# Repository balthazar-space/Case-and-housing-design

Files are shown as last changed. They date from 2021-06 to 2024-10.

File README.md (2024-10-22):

# Balthazar

Open-hardware laptop computer modules description and concept.

These are designs of  modules as presented at https://balthazar.space/wiki/Balthazar with the main aim for team access. See the [main repository](https://github.com/balthazar-space/balthazar) for other designs.

# Balthazar case and design 

Balthazar's casing or a housing and its design.

This is the place for pictures of casing design and 3D ready-to-print files and other design proposals.

A new reorganisation of the files starting from the 1st ever version v0.1, going over to the current v0.2.

Each future version will have its iteration version, containing pictures of made elements and assembled casings, Blender models, 
3D print-ready files, documentation usually encapsulated in README.md file, and adjoining extra files to ease and explain assembly process. 
We will try to accomodate all of the aspects. 

In the case of modifying the case, we encourage you to precisely indicate and include short descriptions of casing openings 
to a certain SoM (systems on a Module) and outputs.

Those files will be updated as we move on and as revisions change to a final look and also materials will vary.
We will ensure that home and industrial versions are made, so that everyone can make case, wheather as a school project, 
cheaper home D-I-Y or ready for a mass production.

About the file formats - the truth is following.
The issues we are encountering and it is as it might be
somewhat problematic with Open Source software. 
CAD is complicated on Linux, as it is a big
business - and we must fight for it to have it more open.

However to be more professional in those both directions, we will try to be reluctantly compliant, 
balancing between the industry and our community.  

You can watch .dxf files only with Autocad software and also on your mobile 
device with a few dedicated apps. 
DWG files you can see also with Adobe programs, but because they are
basically all just drawings they will be shown as 2d drawings then. 
Only in Autocad you can see them as 3D objects.
So you see the dxf files, but if you have no Autocad, you can not do anything with them.
Bummer that is and out of our reach, right now.

Also there are hi res .step files as well as .stl.
Those should be pretty much compatible with many Open Source software and industrial standards.

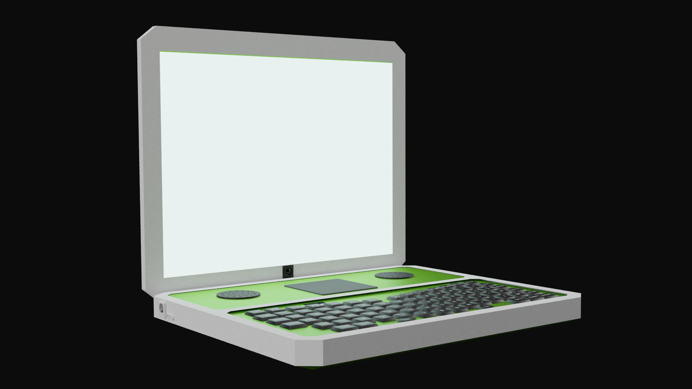
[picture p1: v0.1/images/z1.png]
v0.1


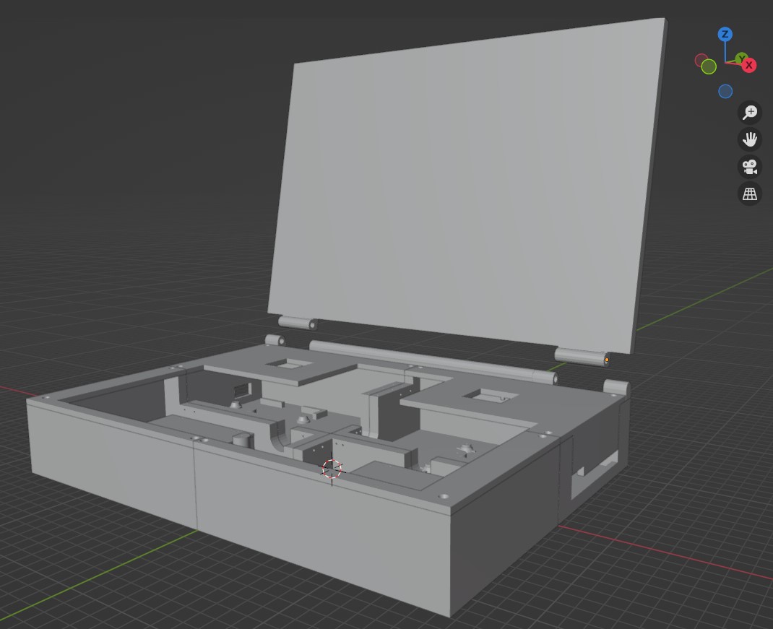
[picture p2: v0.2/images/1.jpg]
v0.2


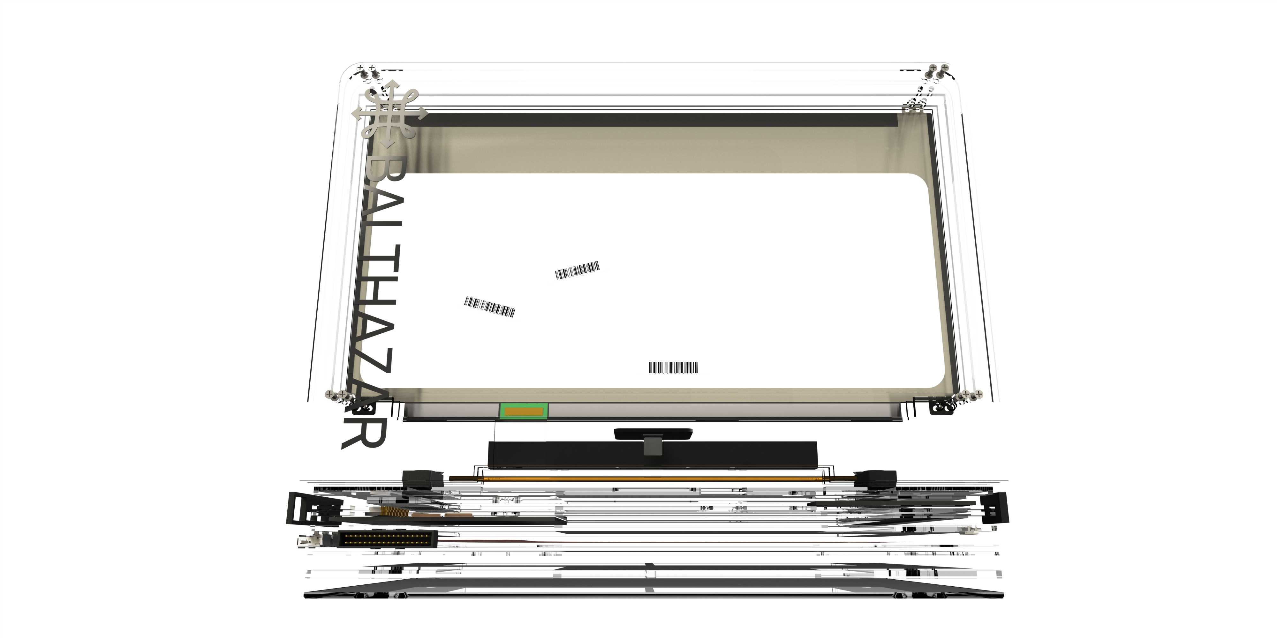
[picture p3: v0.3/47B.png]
v0.3


## License

All resources licensed under the CERN Open Hardware Licence CERN-OHL W V.2.0

Version 2.0 of the CERN-OHL introduces three variants of the licence – strongly (S) reciprocal, weakly (W) reciprocal and permissive (P) – which aim to address specific constraints caused by different collaboration models currently used in open-hardware projects. 

The first two variants mean that if any product is made using an open hardware design, the design of that product, including any improvements or modifications, should be made available under the same licence as that of the original product. Permissive licences do not impose this condition.

See the [LICENSE.md](./LICENSE.md) file for more information.

## Funding

This project is funded through the [NGI Zero Entrust Fund](https://nlnet.nl/entrust), a fund
established by [NLnet](https://nlnet.nl) with financial support from the European Commission's
[Next Generation Internet](https://ngi.eu) program. Learn more on the [NLnet project page](https://nlnet.nl/project/Balthazar-Casing/).

[NLNet foundation logo](https://nlnet.nl)
[NGI0 Entrust Logo](https://nlnet.nl/entrust)

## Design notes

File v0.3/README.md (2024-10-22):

# Bathazar case current 0.3 version 

This is 0.3 version of our new layered design, primarily meant as a final technical set-up with upcoming proper measuraments for 
fitting internal modules.

Preview files are  in .stl, together with .step files for laser cutting.. 
Also a lot more on:

https://balthazar.space/wiki/Case_design

## Funding

This project is funded through the [NGI Zero Entrust Fund](https://nlnet.nl/entrust), a fund
established by [NLnet](https://nlnet.nl) with financial support from the European Commission's
[Next Generation Internet](https://ngi.eu) program. Learn more on the [NLnet project page](https://nlnet.nl/project/Balthazar-Casing/).

[NLNet foundation logo](https://nlnet.nl)
[NGI0 Entrust Logo](https://nlnet.nl/entrust)

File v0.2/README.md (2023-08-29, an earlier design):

# Bathazar case current 0.2 version 3D preview. 

This is 0.2 version of our new design, primarily meant as a technical set-up with proper measuraments for fitting internal modules.

So current no-design or a suitcase-design will not be final, but this phase solves the tecnical issues and a construction system.

Also it is compartmentalised to ease printing on a home 3D printer, reinforced with connecting pegs, thus adding extra stability and sturdiness to the assembled case. 

Printing files are to be found in STL_Print_Case folder, together with assembly instructions. 
Casing parts are stiched together with plastic pins. 
Also you need a good stash of M3 screws to fasten the connecting and overlaying parts, and PCB modules and a keyboard. 
Those are designed with marked dedicated holes.
Also supplied is printable version of assembly procedure.

Below are general overview of the parts, modules and hands-on examples during the assembly.

### Blender



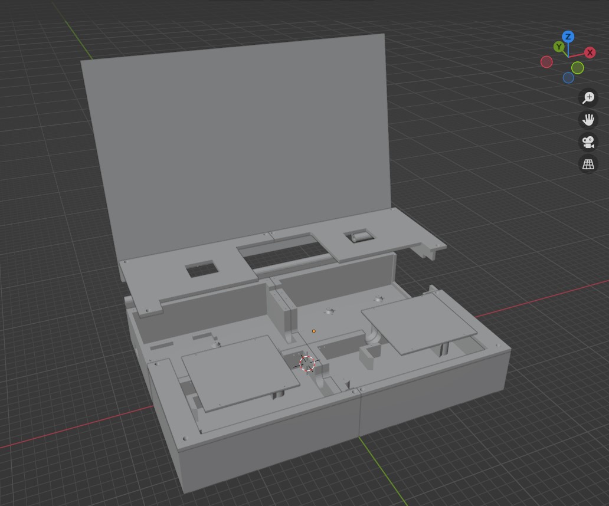
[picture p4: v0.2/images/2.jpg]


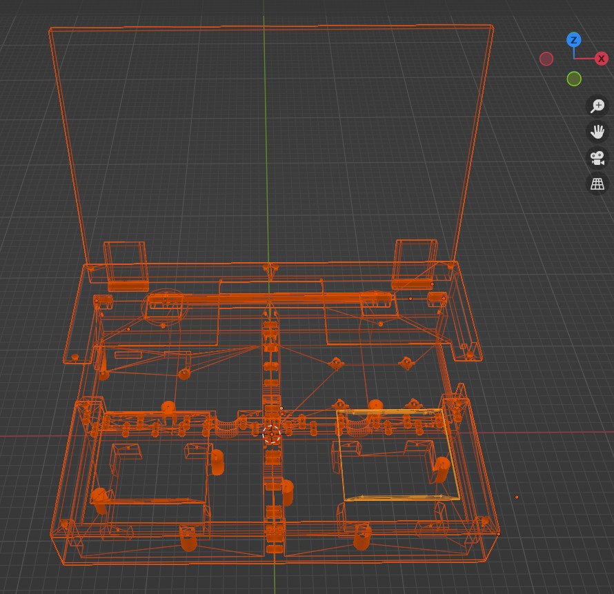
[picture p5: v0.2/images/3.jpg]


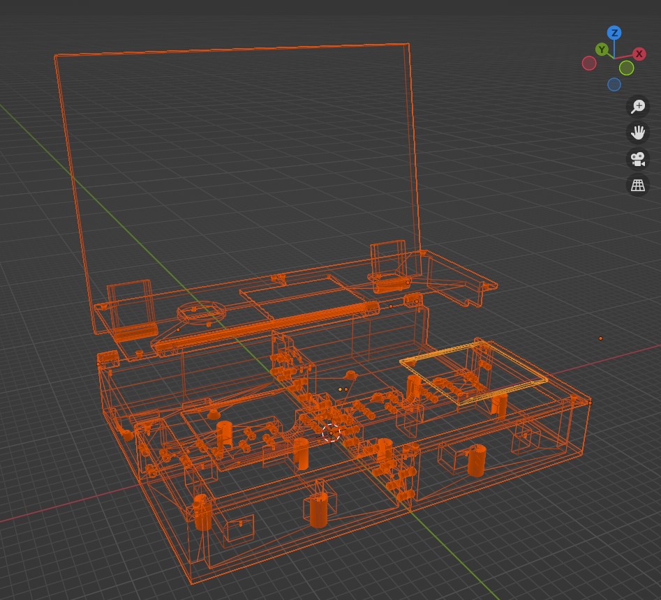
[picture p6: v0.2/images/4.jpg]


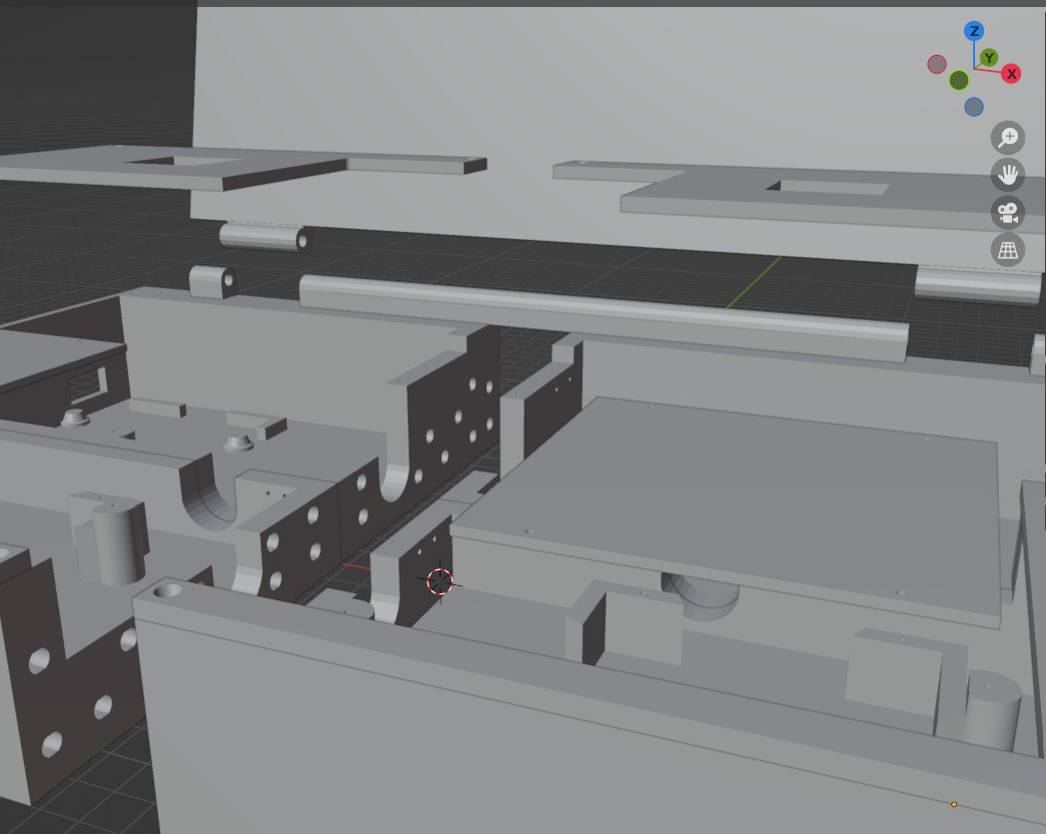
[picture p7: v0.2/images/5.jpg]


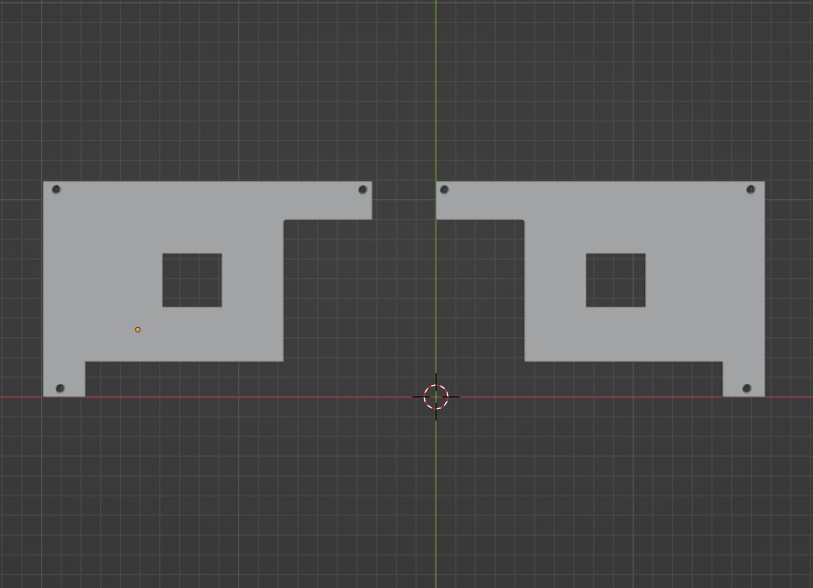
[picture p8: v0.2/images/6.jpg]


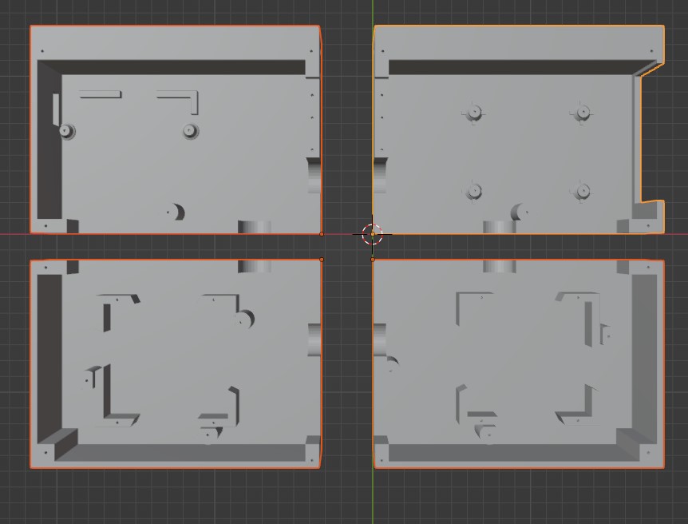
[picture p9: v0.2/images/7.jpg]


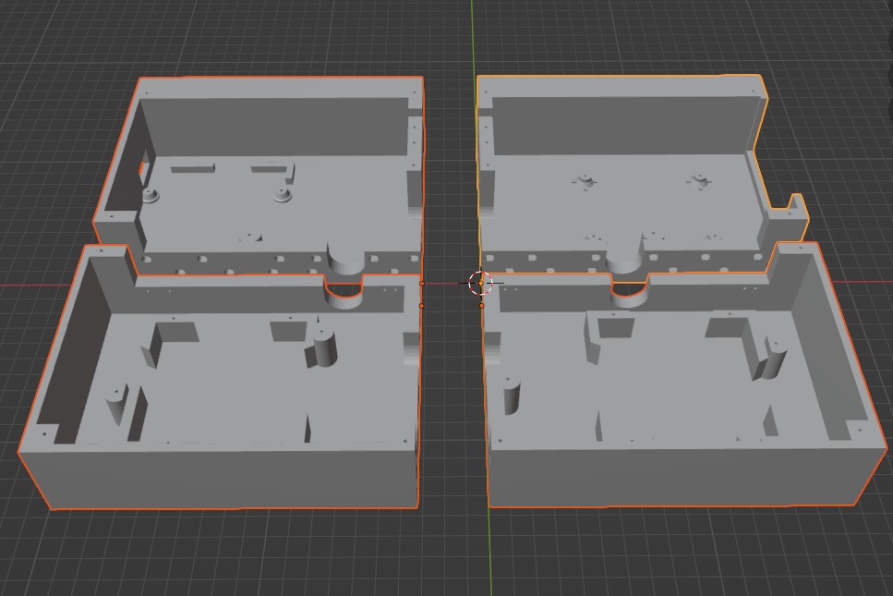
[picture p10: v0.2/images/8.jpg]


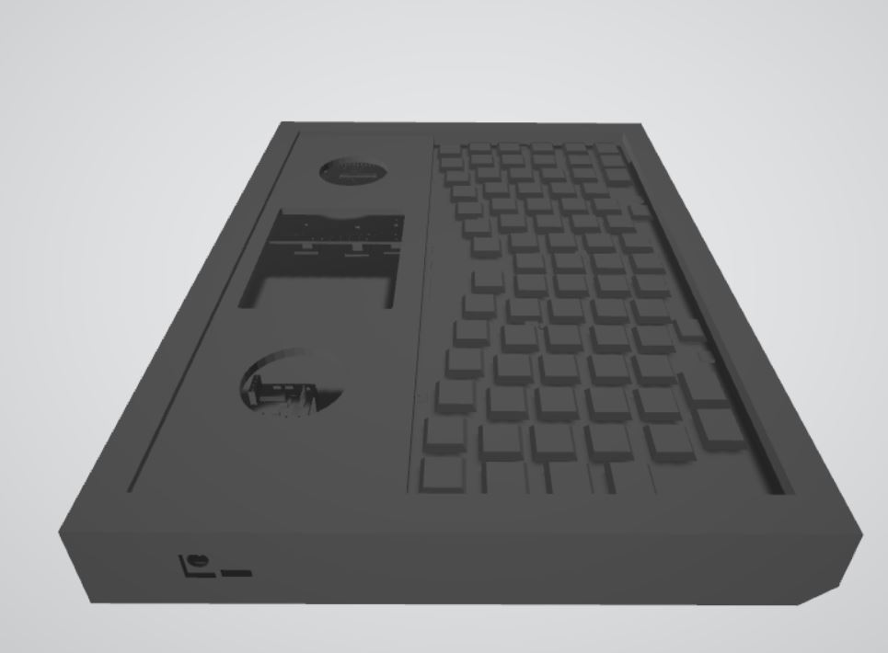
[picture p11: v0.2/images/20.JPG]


### DIY printed parts

#### Case Building block

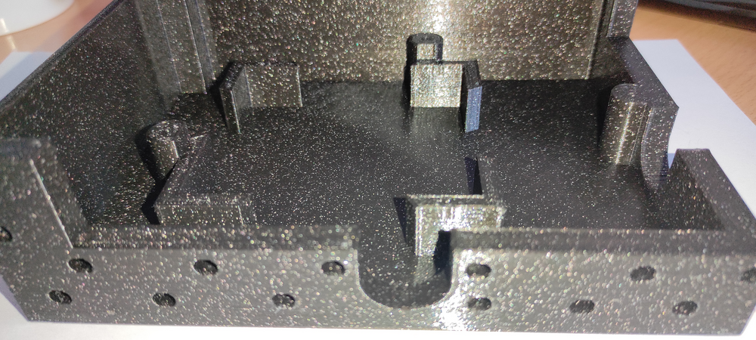
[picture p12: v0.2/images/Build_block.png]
Build_Block


#### Case Building block with connectors

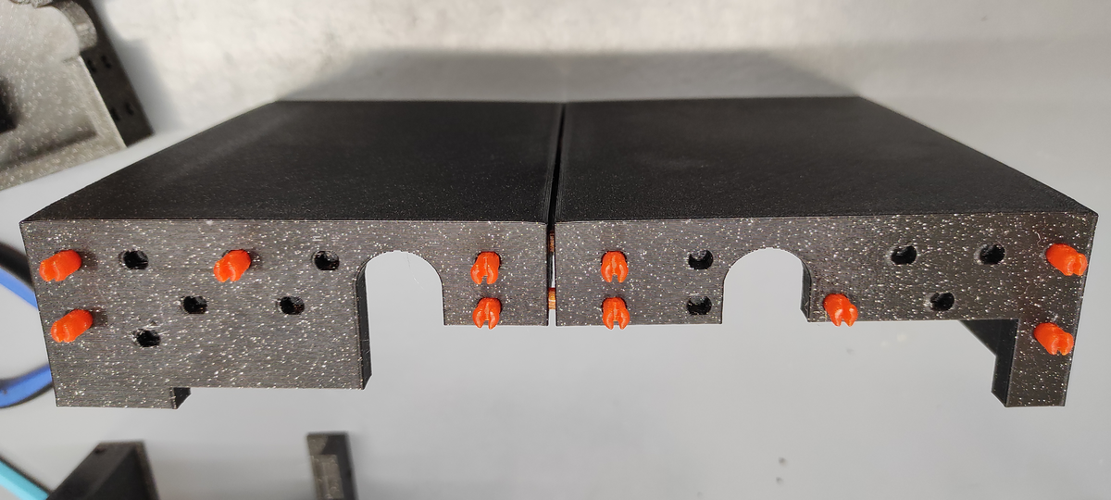
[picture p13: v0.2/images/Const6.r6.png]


#### Botom side

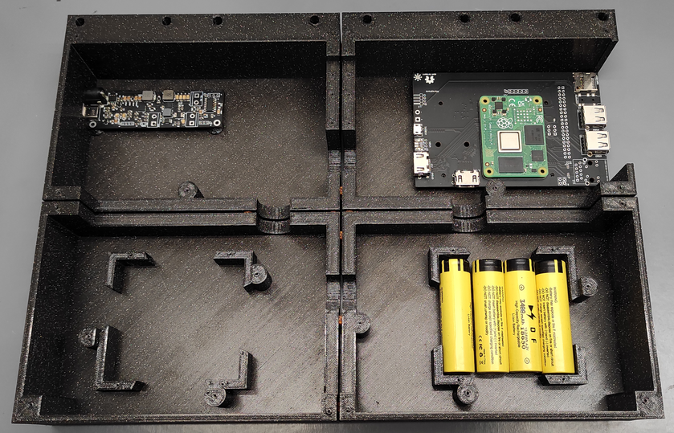
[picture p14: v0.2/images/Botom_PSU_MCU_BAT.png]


![BuildBlockAndC](images/Bottom_PSU_MCU_BAt_cover.png

![BuildBlockAndC](images/Bottom_main_keyb_psu.png

![BuildBlockAndC](images/Botom_Cover_Keyboard.png

#### Side view

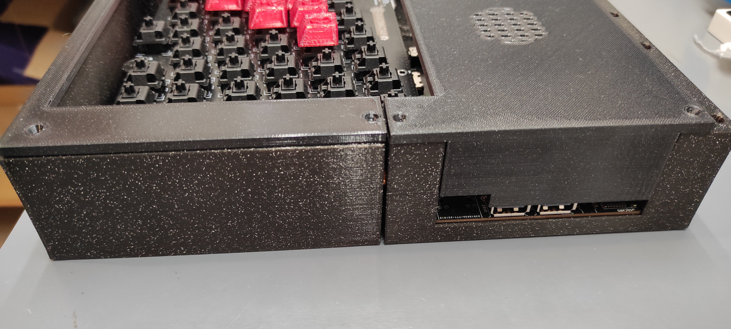
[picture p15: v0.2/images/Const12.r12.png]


#### Assembly

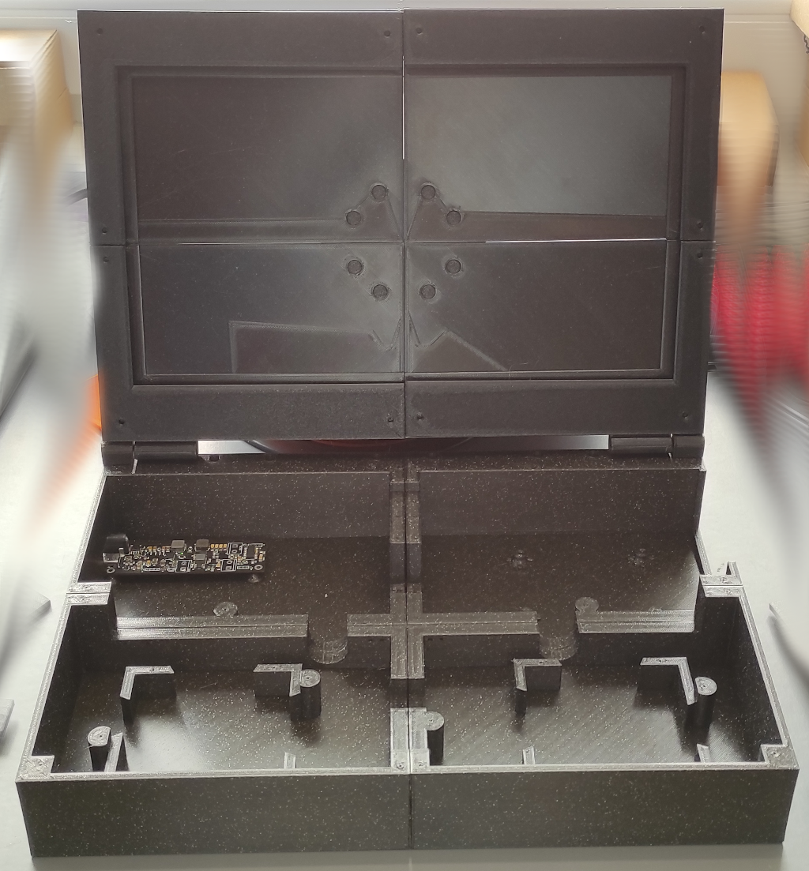
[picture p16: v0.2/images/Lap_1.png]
Lap_1


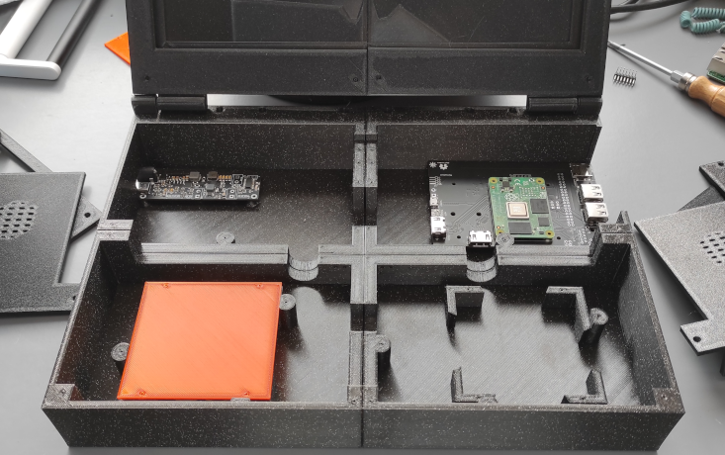
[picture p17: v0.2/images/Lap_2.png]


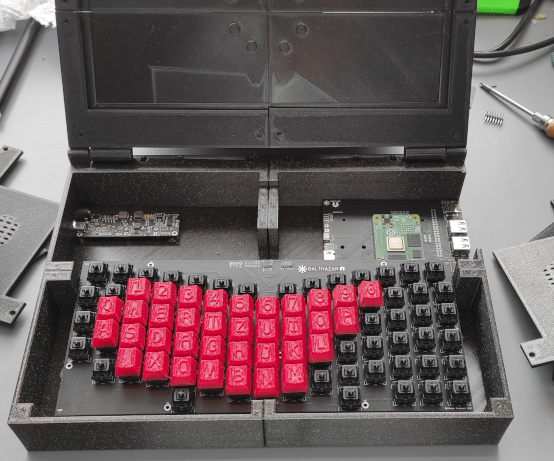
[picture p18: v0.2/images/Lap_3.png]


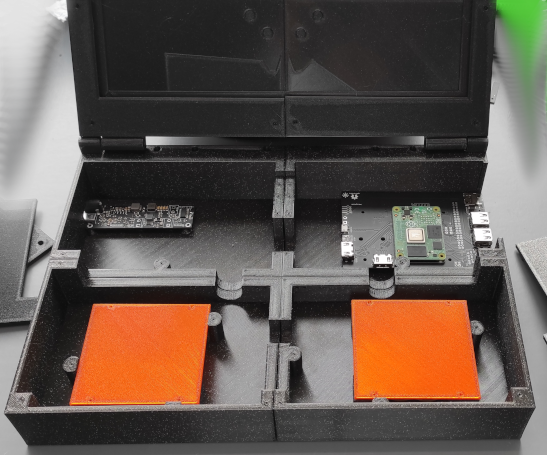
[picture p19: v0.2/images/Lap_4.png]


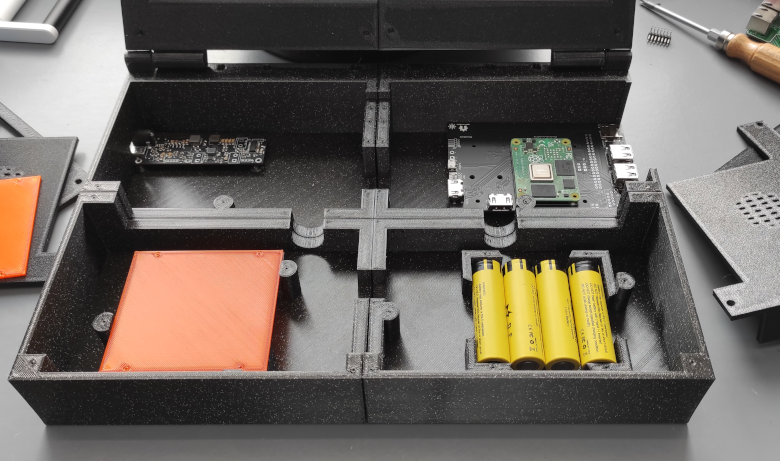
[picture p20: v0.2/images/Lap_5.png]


### LCD cover

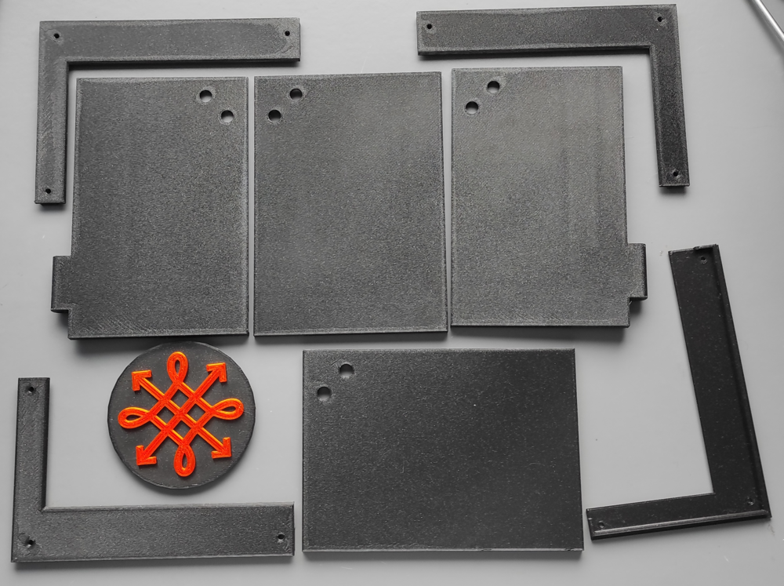
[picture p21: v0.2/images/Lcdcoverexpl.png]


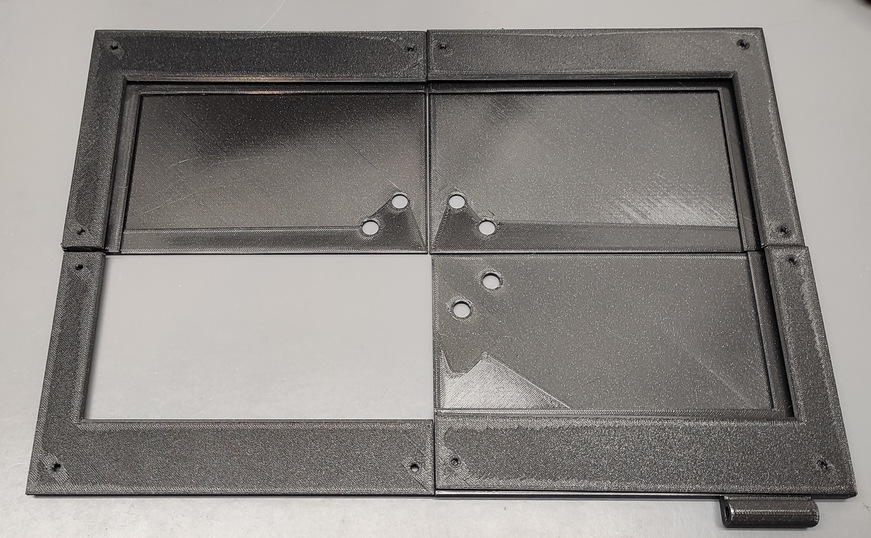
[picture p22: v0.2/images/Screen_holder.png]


BuildBlockAndC

## Funding

This project is funded through the [NGI Zero Entrust Fund](https://nlnet.nl/entrust), a fund
established by [NLnet](https://nlnet.nl) with financial support from the European Commission's
[Next Generation Internet](https://ngi.eu) program. Learn more on the [NLnet project page](https://nlnet.nl/project/Balthazar-Casing/).

[NLNet foundation logo](https://nlnet.nl)
[NGI0 Entrust Logo](https://nlnet.nl/entrust)

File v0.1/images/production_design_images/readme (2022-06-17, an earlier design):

Those are production moulding designs. They are not final, but will not variate too much from the final design.

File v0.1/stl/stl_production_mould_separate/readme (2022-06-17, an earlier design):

Those are files created for production mouldings or hi-def print.
Those are not the final designs, but very little will change as we adopt those during and after the designing the chassis and a hinge system.

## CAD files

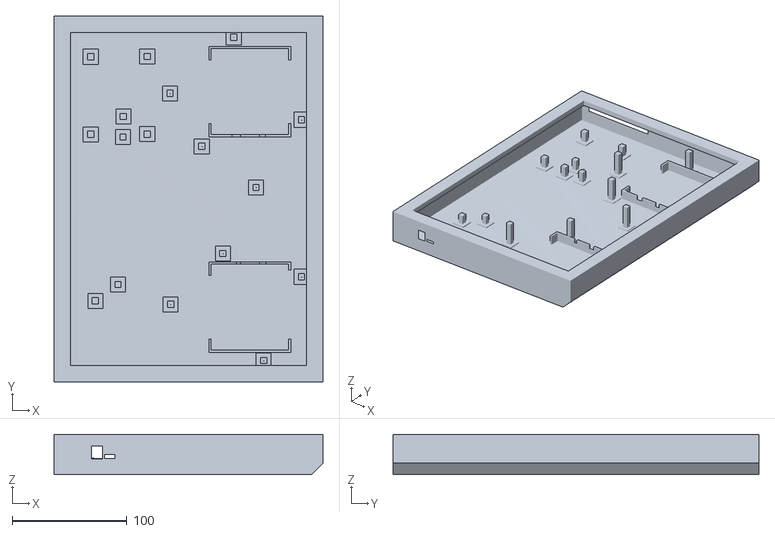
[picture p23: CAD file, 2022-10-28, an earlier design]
v0.1/stl/case_dimensioning.obj
234.6 x 319.2 x 35.2

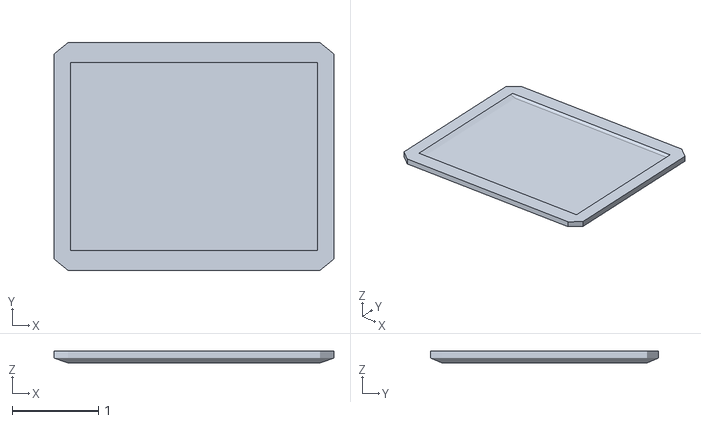
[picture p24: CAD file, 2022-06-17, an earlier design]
v0.1/stl/stl_production_mould_separate/case_3.stl
3.24 x 2.63 x 0.137

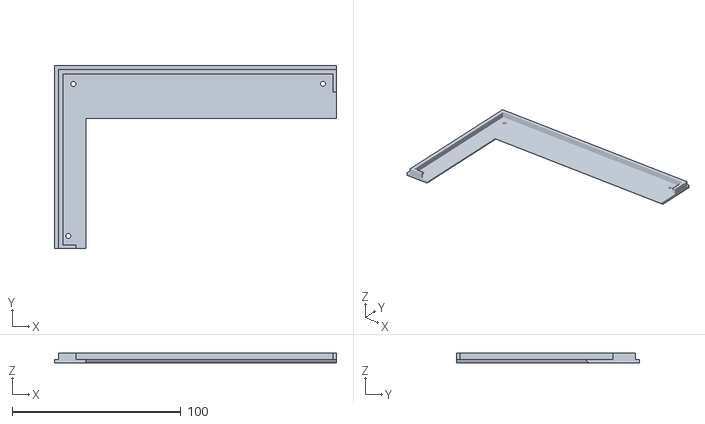
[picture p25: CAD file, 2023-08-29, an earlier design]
v0.2/STL_Print_Case_v0.2/LCD_Holder_top_side_4.stl
167.0 x 108.5 x 6.00

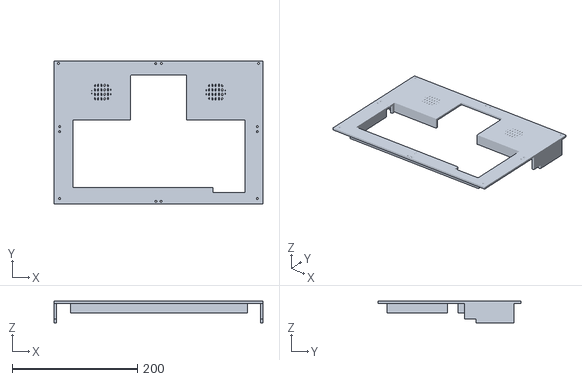
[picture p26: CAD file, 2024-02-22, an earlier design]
v0.2/thinkpad_Keyboard Frame-X2xx-v0.2/Print_files_STL/stl-print files/all customize parts.stl
334.2 x 229.4 x 34.6

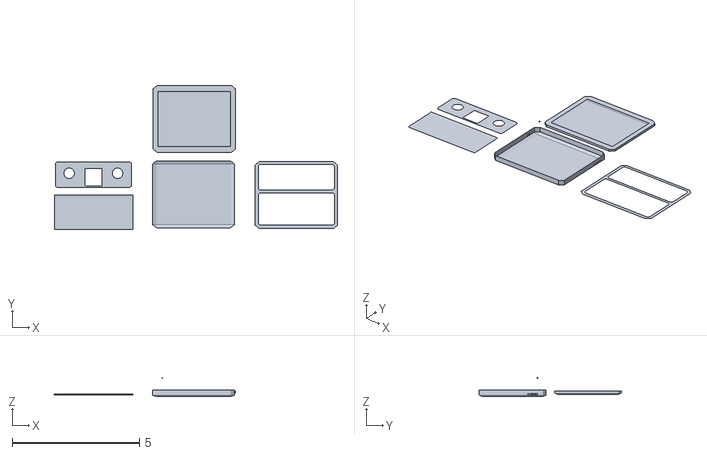
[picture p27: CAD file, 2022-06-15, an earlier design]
v0.1/stl/production_mouldings_recent .stl
11.1 x 5.67 x 1.77

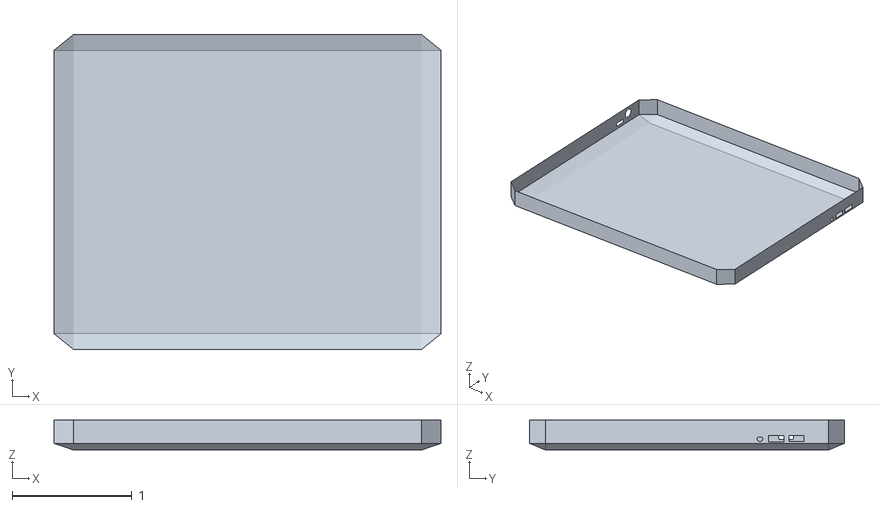
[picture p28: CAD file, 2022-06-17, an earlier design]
v0.1/stl/stl_production_mould_separate/case_4.stl
3.24 x 2.63 x 0.251

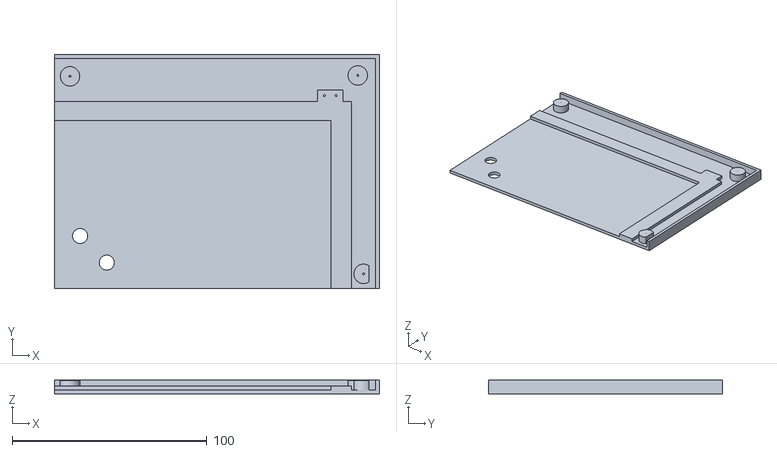
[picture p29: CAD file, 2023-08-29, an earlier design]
v0.2/STL_Print_Case_v0.2/LCD_Holder_bottom_side_up_right.stl
167.0 x 120.0 x 7.00

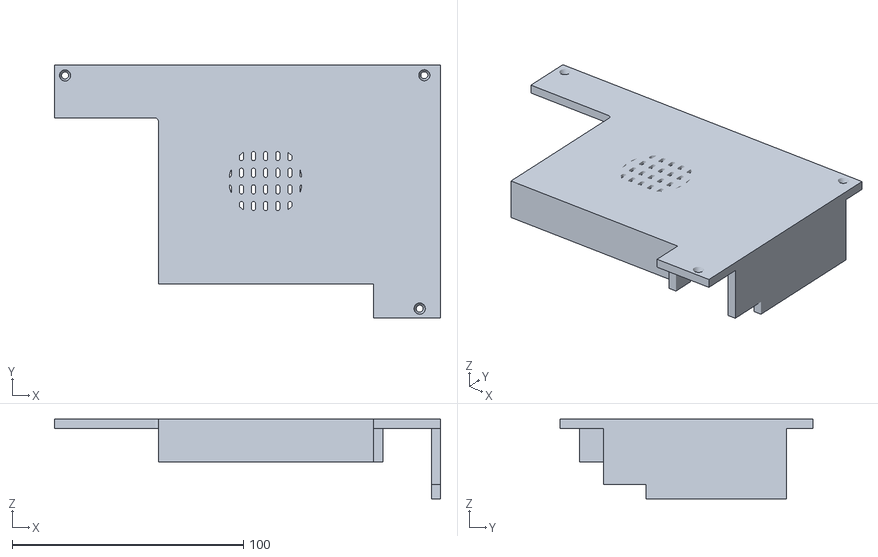
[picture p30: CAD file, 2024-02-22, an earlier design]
v0.2/thinkpad_Keyboard Frame-X2xx-v0.2/Print_files_STL/stl-print files/top_right_part.stl
167.0 x 109.4 x 34.6

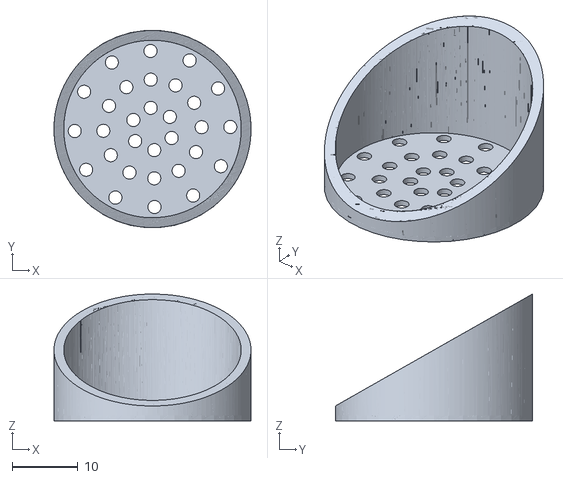
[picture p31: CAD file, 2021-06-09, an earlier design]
v0.1/stl/speakerTilt.stl
30.0 x 30.0 x 19.3

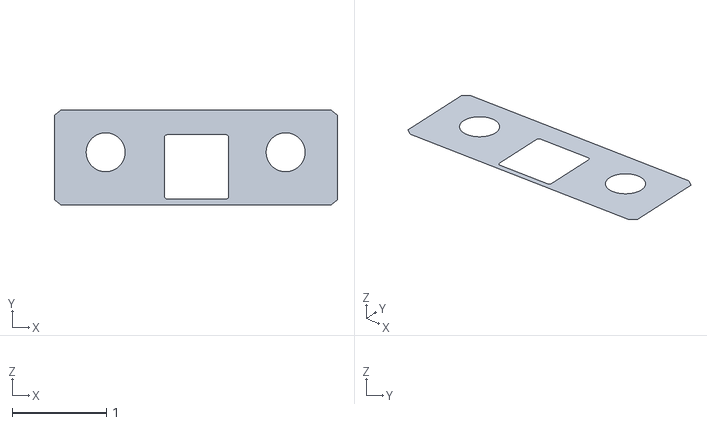
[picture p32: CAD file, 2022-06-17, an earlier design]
v0.1/stl/stl_production_mould_separate/case_1.stl
3.00 x 1.01 x 0

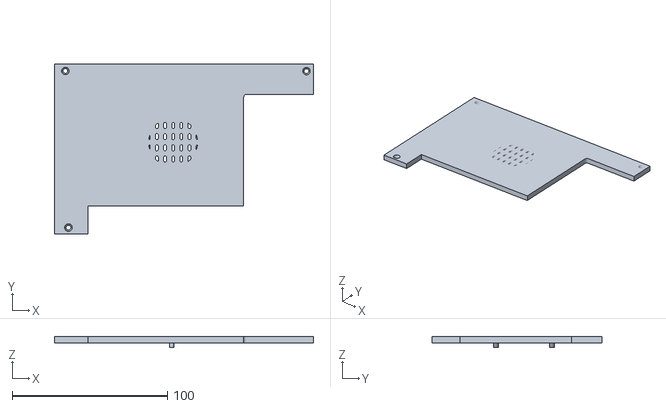
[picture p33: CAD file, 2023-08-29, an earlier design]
v0.2/STL_Print_Case_v0.2/CASE_top_up_left.stl
167.0 x 109.4 x 6.92

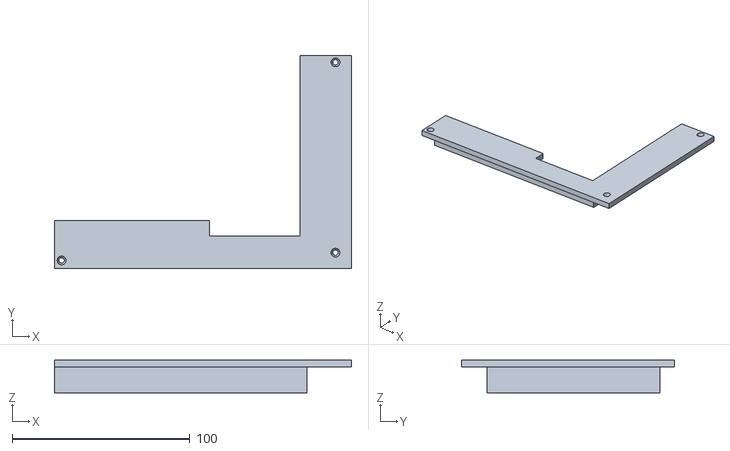
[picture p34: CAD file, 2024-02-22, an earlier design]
v0.2/thinkpad_Keyboard Frame-X2xx-v0.2/Print_files_STL/stl-print files/bottom_right_part.stl
167.0 x 119.9 x 18.5

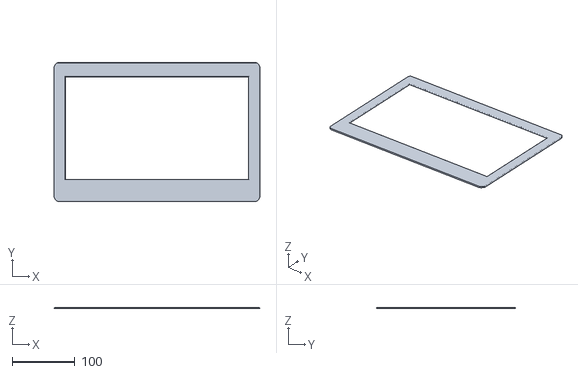
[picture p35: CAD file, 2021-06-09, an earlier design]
v0.1/stl/ScreenFront.stl
327.8 x 221.7 x 2.04

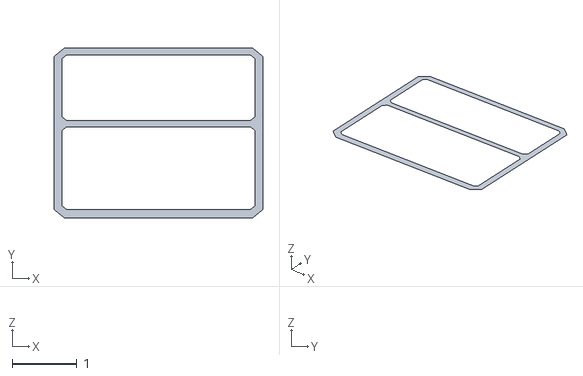
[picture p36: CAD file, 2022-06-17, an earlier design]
v0.1/stl/stl_production_mould_separate/case_5.stl
3.24 x 2.63 x 0

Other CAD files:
v0.1/dxf+dwg/#topKeys1.dxf
v0.1/dxf+dwg/#screenBack1.dxf
v0.1/dxf+dwg/bodyDown.dxf
v0.2/STL_Print_Case_v0.2/CASE_bottom_down_right.stl
v0.1/dxf+dwg/bodyDown.dwg
v0.1/dxf+dwg/screenBack1.dwg
v0.1/dxf+dwg/screenBack1.dxf
v0.1/dxf+dwg/screenFront.dwg
v0.1/dxf+dwg/screenFront.dxf
v0.1/dxf+dwg/topKeys.dwg
v0.1/dxf+dwg/topKeys.dxf
v0.1/dxf+dwg/topKeys1.dxf
v0.1/stl/bodyDown1.stl
v0.1/stl/screenBackGrid.stl
v0.1/stl/stl_production_mould_separate/case_2.stl
v0.1/stl/topKeys.stl
v0.2/STL_Print_Case_v0.2/BATTERY_Cover.stl
v0.2/STL_Print_Case_v0.2/CASE_bottom_down_left.stl
v0.2/STL_Print_Case_v0.2/CASE_bottom_up_left.stl
v0.2/STL_Print_Case_v0.2/CASE_bottom_up_right.stl
v0.2/STL_Print_Case_v0.2/CASE_top__up_right.stl
v0.2/STL_Print_Case_v0.2/CASE_top_down_left.stl
v0.2/STL_Print_Case_v0.2/CASE_top_down_right.stl
v0.2/STL_Print_Case_v0.2/Hinge_holder_and_connector.stl
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

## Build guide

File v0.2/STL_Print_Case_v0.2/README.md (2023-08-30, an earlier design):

Here you can find .stl files of the casing that are ready to print on your home 3D printer. 
The whole casing is envisaged to be printed on smaller home 3D printer, basically it is compartmentalised in 4 elements that make the whole 13.3" dimension of the case.
Those files are ready to be used on higher resolution Prusa type 3D printer.

Additionally one needs M2 screws to fasten Balthazar modules inside, also to fasten covers for the keyboard and cover for LCD.

• 3D PRINTED BATTERY COVER x 2

• 3D PRINTED UNIVERSAL CONNECTOR (pegs) x 100

• BAG OF SCREWS 8 x M2 x 6mm 24 x M2 x 10mm

• METAL or PRINTED BARS 2 x 58 x 5mm

Detailed procedure with pictures can be followed in supplied Assembly.pdf file in this folder.
 
A quick assembly procedure and its description is as follows:

a) Print each .stl file once, except 2x BATTERY Cover, 100 pieces of Universal Connector pegs, that are needed to connect the elements of the lower casing.

b) Put 4 Case Bottom elements together by inserting the pegs (Universal Connector) into the corresponding holes and fasten those together, snapping those into one sturdy unit.

c) Position PCB modules, keyboard and battery packs into the place and screw those in with M2 screws. 

d) Place the 4 Case Top elements on the top of the assembled base and fasten those with M2 screws.

f) Screw the Hinge Holder on with 3 M2 screws on the each side.

e) Assemble 4 LCD Holders Bottom side 

f) Insert the 13.3" screen

g) Screw on 4 elemnets of LCD holder Top side.

h) Snap LCD Logo into outer LCd Holder middle the place.

i) Align hinges and push through Hinge Long rotate rod through until it is locked in place.

That completes basic casing assembly.

As this is ongoing design and development certain things and procedures might change and those will be updated, as progress is made.

A file that will ease assembly even more is supplied as Assembly.pdf.

## Funding

This project is funded through the [NGI Zero Entrust Fund](https://nlnet.nl/entrust), a fund
established by [NLnet](https://nlnet.nl) with financial support from the European Commission's
[Next Generation Internet](https://ngi.eu) program. Learn more on the [NLnet project page](https://nlnet.nl/project/Balthazar-Casing/).

[NLNet foundation logo](https://nlnet.nl)
[NGI0 Entrust Logo](https://nlnet.nl/entrust)

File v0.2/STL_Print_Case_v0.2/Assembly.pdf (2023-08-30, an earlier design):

# Assembly documentation

# BALTHAZAR

## a Personal Computing Device

## This manual will guide you through the steps

required to assemble Balthazar's case.

### 1. DOWNLOAD CASE STL FILES

- Battery_cover.stl
- CASE_bottom_down_left.stl
- CASE_bottom_down_right.stl
- CASE_bottom_up_left.stl
- CASE_bottom_up_right.stl
- CASE_top_up_right.stl
- CASE_top_down_right.stl
- CASE_top_up_left.stl
- Hinge_holder_and_connector.stl
- Hinge_long_rotate_45_on_Z_to_fit_prusa_mini.stl
- LCD_Holder_bottom_side_down_left.stl
- LCD_Holder_bottom_side_down_right.stl
- LCD_Holder_bottom_side_up_left.stl
- LCD_Holder_bottom_side_up_right.stl
- LCD_Holder_top_side_1.stl
- LCD_Holder_top_side_2.stl
- LCD_Holder_top_side_3.stl
- LCD_Holder_top_side_4.stl
- LCD_LOGO_Connector.stl
- Universal_Connector_for_case.stl

### 2. REQUIRED CONTENT

- 3D PRINTED PARTS
- 3D PRINTED BATTERY COVER x 2
- 3D PRINTED UNIVERSAL CONNECTOR x 100
- BAG OF SCREWS 8 x M2 x 6mm
24 x M2 x 10mm
- | METAL BARS | 2 x 58 x 5mm

# 3. CONNECT THE BOTTOM PARTS OF THE CASE WITH CONNECTORS

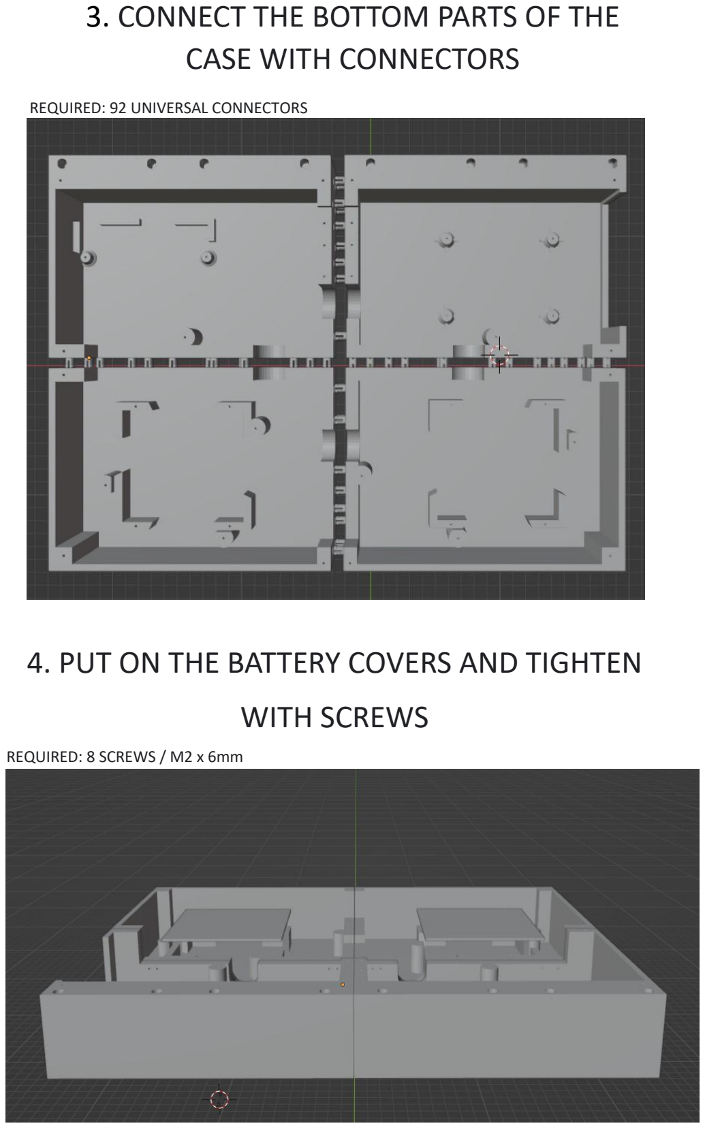
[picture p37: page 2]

# 4. PUT ON THE BATTERY COVERS AND TIGHTEN

# WITH SCREWS

REQUIRED: 8 SCREWS / M2 x 6mm

REQUIRED: 92 UNIVERSAL CONNECTORS

# 5. ASSEMBLE THE LAPTOP COVER

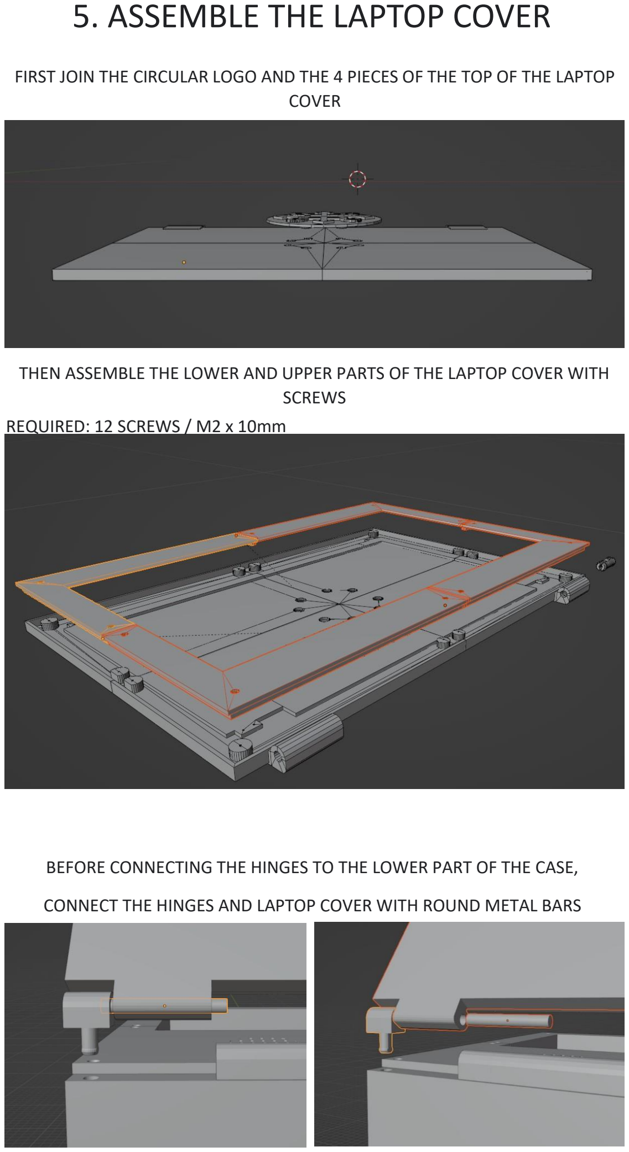
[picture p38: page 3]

FIRST JOIN THE CIRCULAR LOGO AND THE 4 PIECES OF THE TOP OF THE LAPTOP COVER

THEN ASSEMBLE THE LOWER AND UPPER PARTS OF THE LAPTOP COVER WITH SCREWS

BEFORE CONNECTING THE HINGES TO THE LOWER PART OF THE CASE,

CONNECT THE HINGES AND LAPTOP COVER WITH ROUND METAL BARS

REQUIRED: 12 SCREWS / M2 x 10mm

# 5. PRESS THE CONNECTORS INTO THE HINGES AND THEN INTO THE LOWER PART OF THE CASE

REQUIRED: 8 UNIVERSAL CONNECTORS

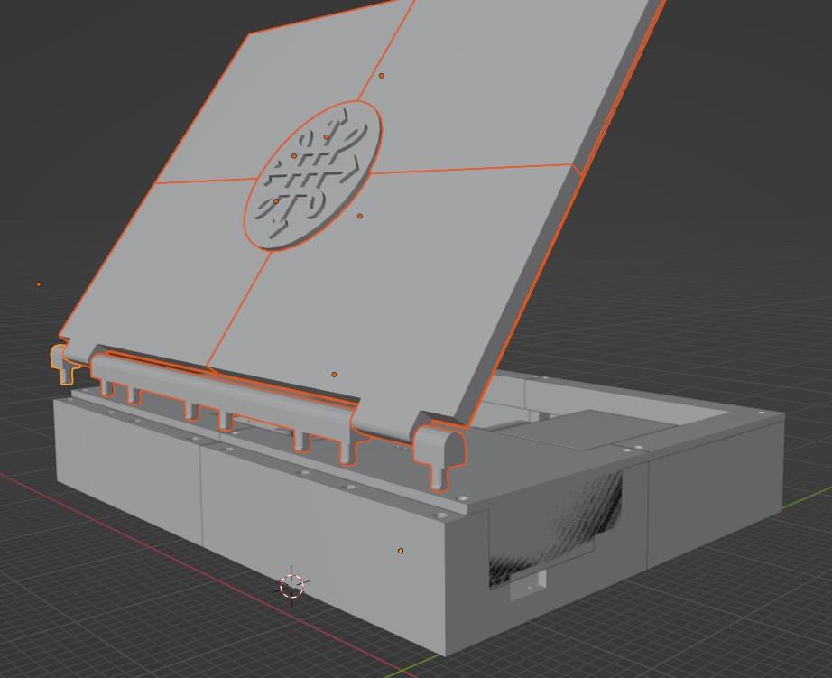
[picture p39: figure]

# 6. ASSEMBLE THE TOP ELEMENTS OF THE CASE

# WITH SCREWS

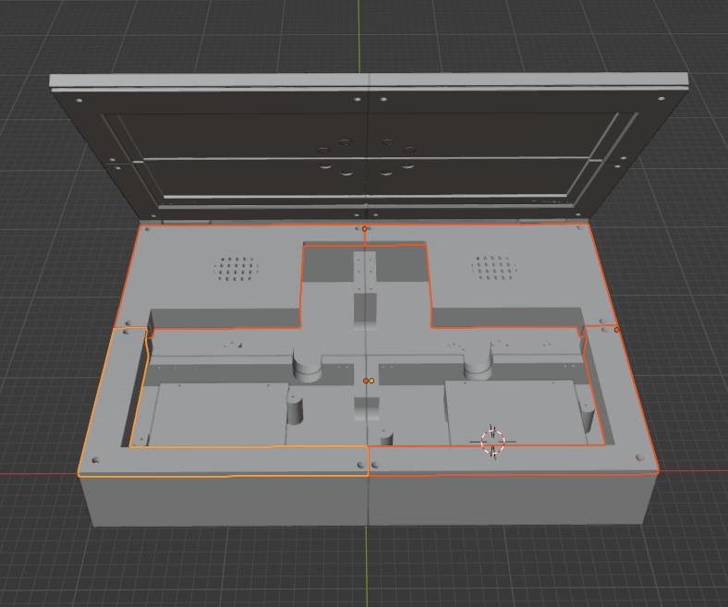
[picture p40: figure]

REQUIRED: 12 SCREWS / M2 x 10mm

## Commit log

2022-06-15 Add files via upload
    Production mouldings for casing
    [production_mouldings_recent .stl]
2023-08-24 moved to v0.1
    [#screenBack1.dxf, #topKeys1.dxf, ScreenFront.stl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]
2024-02-22 Add files via upload
    ThinkPad Lenovo x2xx keyboard adapter. It fits to a version 0.2 of the housing. Includes click-on keyboard chip USB-C board to connect to the main system - also via I2C.
    [all customize parts.stl, bottom_left_part.stl, bottom_right_part.stl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]
